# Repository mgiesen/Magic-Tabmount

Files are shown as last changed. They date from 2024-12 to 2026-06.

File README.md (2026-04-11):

# Magic Tabmount

Der "Magic Tabmount" ist eine smarte Wandhalterung für das iPad (Generation 5 bis 9). Durch ein integriertes Magnetsystem kann das iPad mit einem Handgriff an der Wand befestigt oder wieder entfernt werden.

Ferner verfügt die Baugruppe über eine integrierte Schaltung, die mittels Radarwellen die Anwesenheit von Personen um das iPad herum detektiert. Werden Personen erkannt, wird das iPad Display aktiviert und bei Abwesenheit deaktiviert.

## Projektmotivation

Insbesondere die älteren iPad Modelle entsprechen heute nur noch selten den Leistungsanforderungen ihrer Nutzer. Aufgrund des geringen Wiederverkaufswerts enden sie entsprechend häufig ungenutzt in der Schublade. Eine Wandmontage ermöglicht verschiedene Anwendungsmöglichkeiten, für die auch eine ältere Hardware noch geeignet ist. Zum Beispiel:

- Smart Home Steuerungszentrale
- Familien Planer
- Musik Steuerungszentrale
- Dashboards für Fitness/ Stromverbrauch etc.
- Ticker und Nachrichten
- und viele mehr...

Ästhetisch war es mir wichtig, das originale Look and Feel des iPads beizubehalten. Um das Gerät scheinbar unsichtbar montieren zu können, wird auf die Geräterückseite ein Magnetring geklebt, der an der iPad Halterung passgenau gehalten wird.

Die automatische Aktivierung des Displays bei Annäherung fühlt sich nicht nur magisch an, sondern spart auch Zeit und erfordert nicht den Einsatz der Hände, was insbesondere beim Kochen nützich ist.

https://github.com/user-attachments/assets/be153968-7474-4deb-8c27-1ca8d5477d2e

## Technische Challange

In erster Linie ist das Projekt eine technische Challange, denn Apple stellt keine Schnittstelle bereit, um den Aktivierungszustand des Displays zu steuern. Für eine gute Nutzbarkeit in geschützem privaten Umfeld war es jedoch wichtig, dass die zuletzt geöffnete App direkt nach Aktivierung des Displays sichtbar wird.

Um auch den notwendigen Zwischenschritt des "Entsperrens" zu umgehen, habe ich mir ein iPad Display Cover näher angesehen. Klappt man dieses zu und wieder auf, wird das iPad bei deaktiviertem Pincode automatisch entsperrt.

Hierzu verfügt das iPad über zwei magnetoresistive Sensoren, die erkennen, dass ein Smart Cover montiert ist und ob dieses auf- oder zugeklappt ist. Mit einer speziellen Folie, lassen sich die im Cover verbauten Magnete sichtbar machen. Die zwei runden Magnete sind für die Sperrung/Entsperrung des Displays erforderlich.

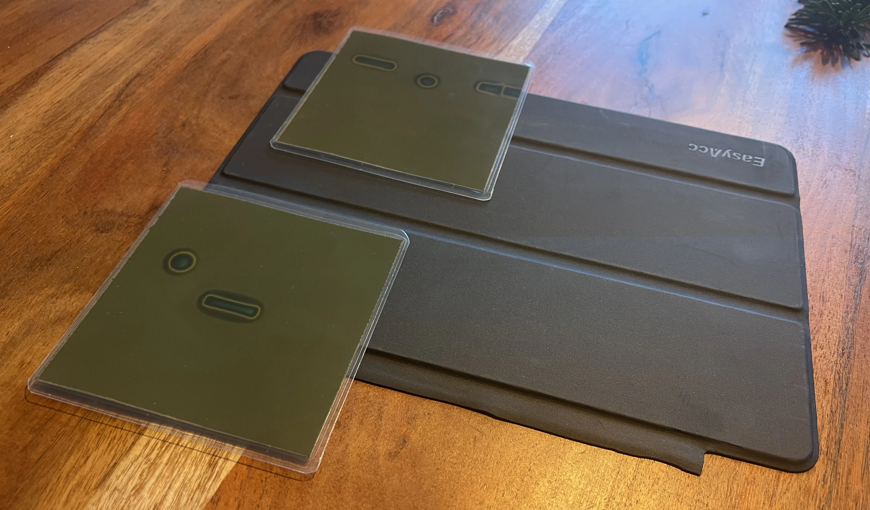
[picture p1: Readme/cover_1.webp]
Cover


## Integrierte Schaltung

Die Wandhalterung positioniert einen Permanentmagneten an der oberen linken Gerätekante, um die Anwesenheit eines Smart Covers zu simulieren. Ein zweiter Magnet an der unteren Geräteseite sperrt das Display bei Anwesenheit und entsperrt es bei Abwesenheit. Stellt man die automatische Displaysperre des iPads aus, kann der Displayzustand vollständig durch den iPad Halter bestimmt werden.

Der Einsatz eines Elektromagneten an der unteren Geräteseite liegt initial auf der Hand. Jedoch ist der im iPad verbaute Magnetsensor auf der Geräteoberseite verbaut. Daher muss ein besonders starkes Magnetfeld aufgebaut werden, welches geeignet ist den Sensor durch Gehäuse, Akku und Display hindurch zu aktivieren. Der Einsatz eines Elektromagneten würde hier zu einem hohen permaneten Stromverbrauch führen.

Daher habe ich mich dazu entschlossen, einen starken Neodymmagnet einzusetzen, der durch einen kleinen Stepper Motor verschoben wird. Dies führt zu einem minimalen Stromverbrauch, da nur beim Änderung des Displayzustandes Energie benötigt wird.

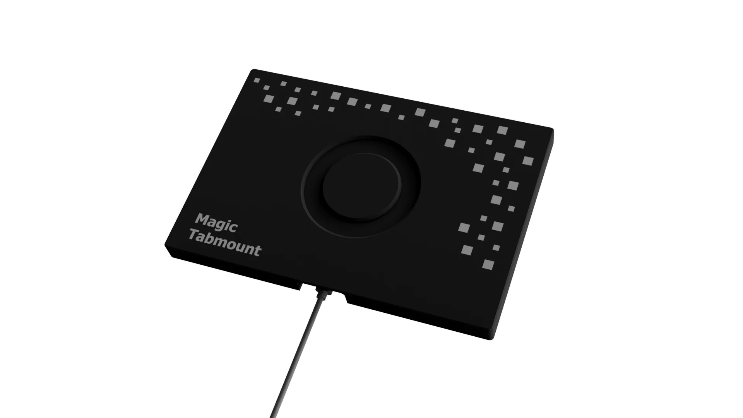
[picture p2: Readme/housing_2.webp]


In Summe integriert die Schaltung entsprechend einen mmWave-Radarsensor, zur Anwesenheitserkennung von Personen, einen kleinen Stepper Motor zur Verschiebung des Magneten, sowie entsprechender Steuerungselektronik.

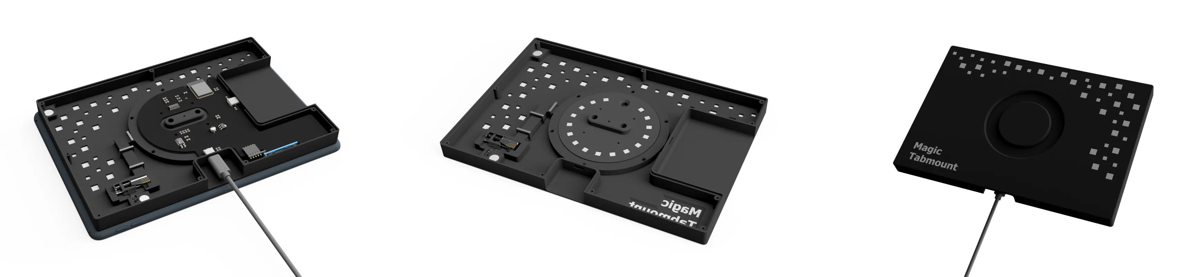
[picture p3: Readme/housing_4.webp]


## Planung der Elektronik

Um den Stromanschluss der Platine mit einer Lademöglichkeit des iPads zu kombinieren, habe ich zwei USB C Anschlüsse auf der Platine verbaut. Der nach unten ausgerichtete Port, ist für ein Stromkabel vorgesehen. Der zweite Port ist auf gleicher Höhe wie der Lightning Anschluss des iPads positioniert. Somit kann ein kurzes Verbindungskabel zwischen iPad und Wandhalterung zum Laden des iPads eingesetzt werden.

Zur Auswertung der Signale und Steuerung der Logik ist ein Mikrocontroller verbaut, der direkt über den Host Port programmiert werden kann. Zur Steuerung des Motors wird zudem ein Stepper Treiber benötigt. Der Umfang der Elektronik und entsprechender Komplexität erfordert ein Custom-PCB Design, welches ich mit KiCad umgesetzt habe.

Für eine besondere, persönliche Note, habe ich das vorderseitige Produktlogo aus Semi-Transparentem Material gedruckt, um es aktiv zu hinterleuchten. Somit integriert die Platine zusätzlich vier RGB LEDs, die über den Mikrocontroller gesteuert werden. Ein rückseitig verbauter Hall-Sensor prüft, ob das iPad anliegt, oder nicht. Sobald das iPad angelegt ist, wird die Logobeleuchtung ausgeschlatet.

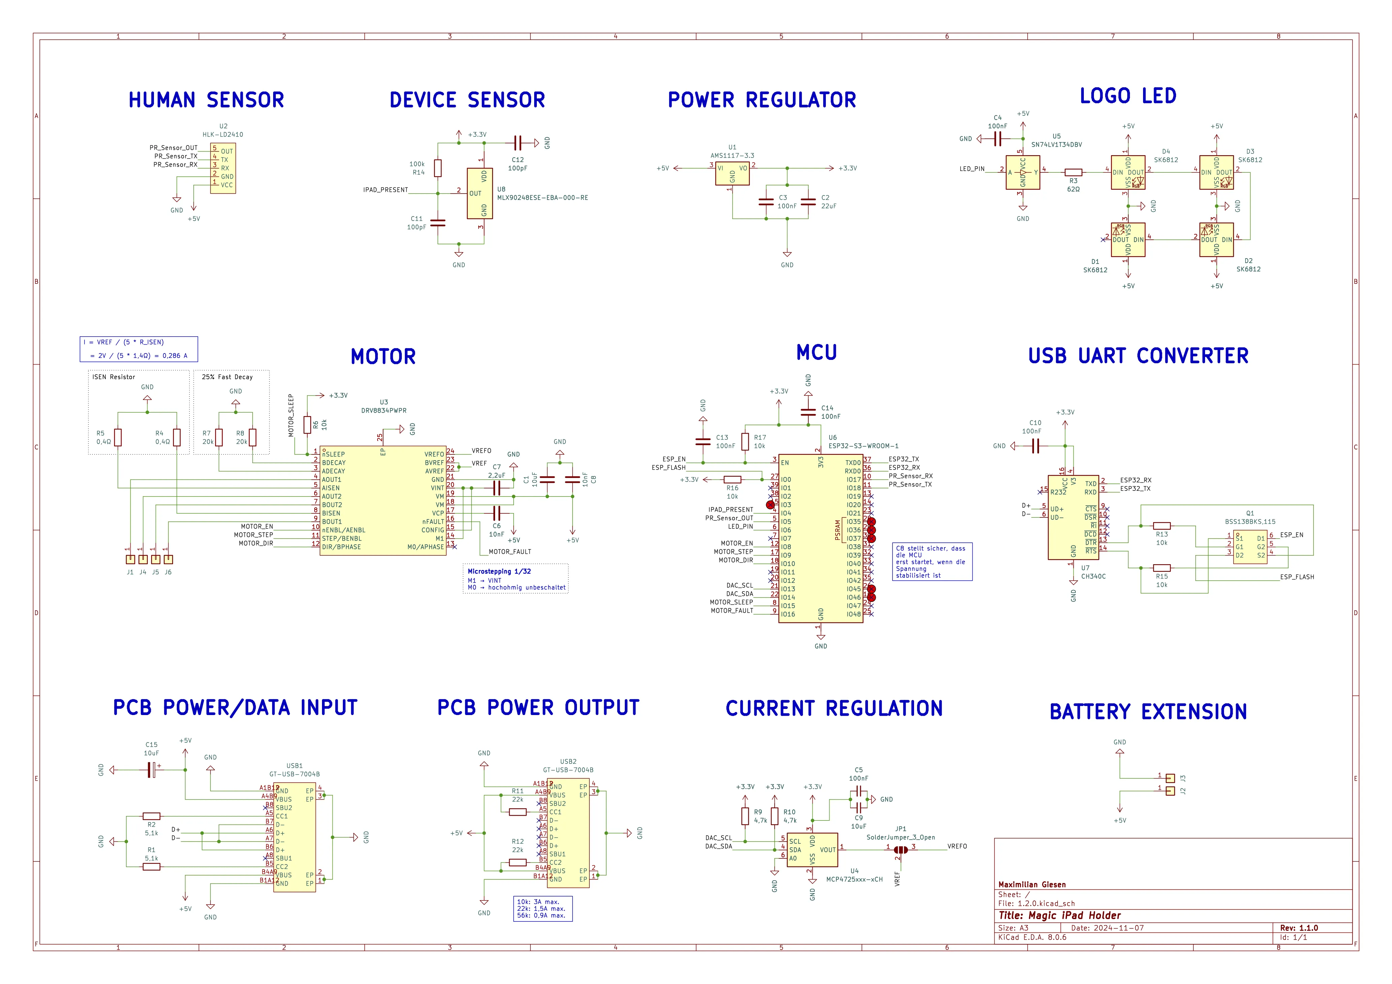
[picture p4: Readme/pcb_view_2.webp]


### PCB Layout

Aufgrund der hohen Anzahl an Elektronik Komponenten, habe ich versucht ausschließlich auf SMD Komponenten zu setzen, sodass ich einen Großteil der Komponetnten mittels Stencil bestücken konnte. Funktionsbedingt musste lediglich der Hall Sensor zur Geräteerkennung, als auch die Logobeleuchtung auf die Unterseite des PCBs gelegt werden.

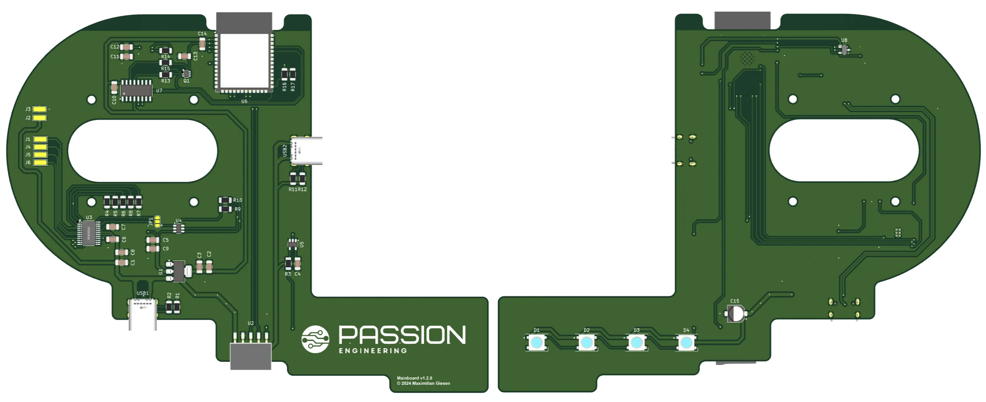
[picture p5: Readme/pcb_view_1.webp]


### Ergebnis

Mittels Stencil und Hot-Plate ließen sich alle Komponenten schnell und einfach verlöten. Das PCB wird mit vier Schrauben im Gehäuse befestigt und der Stepper Motor am Platinenrand verlötet. Für die Zukunft wäre ein Stecker praktikabeler, jedoch war diese Lösung kurzfristig am kostengünstigsten.

Die seitliche Tasche ermöglicht es ein Standard USB C auf Lightning Kabel einzurollen und das Gerät über einen Winkeladapter zu laden.

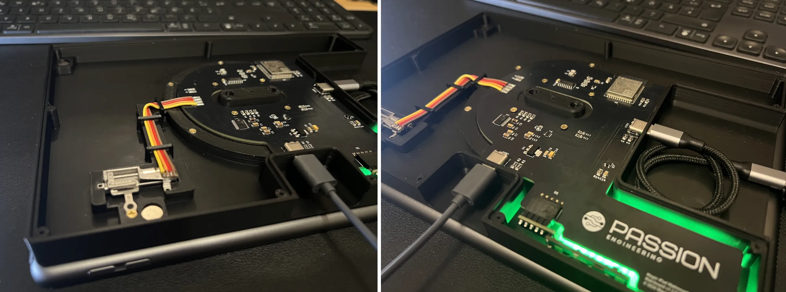
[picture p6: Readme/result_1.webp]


## Gehäuse

Während des Prototypings und ohne sonderlichen Fokus auf einen marketingtauglichen Namen, lief der Wandhalter unter dem Projektnamen "Magic iPad Wallmount". Um keine Markenrechte zu verletzten, änderte ich den Namen zum Projektende auf Magic Tabmount.

Das Gehäusedesign sollte initial kleinstmöglich und funktionsorientiert gestaltet sein.

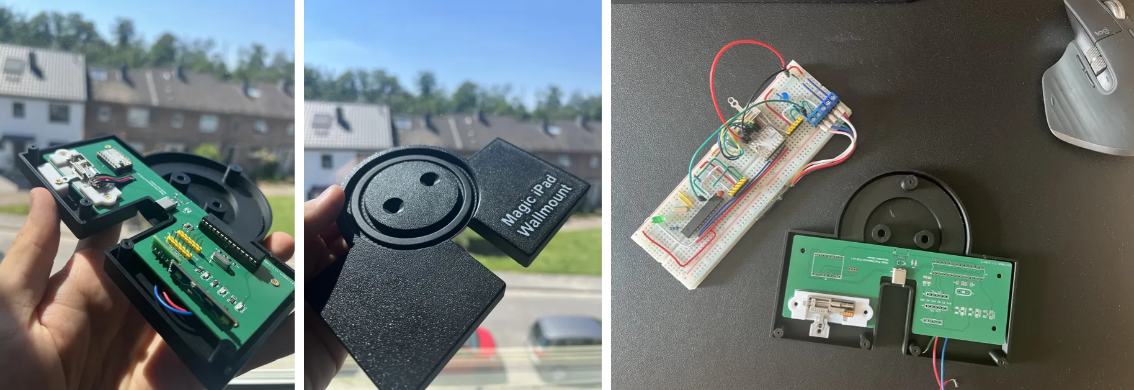
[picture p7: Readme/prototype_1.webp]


Problemtaisch war der Magnet an der oberen Geräteecke, ohne den eine Steuerung des Displays nicht möglich war. Der zuerst aufgeklebte Magnet störte bei der Bedienung des Tablets in der Hand, weswegen ich das Design an die Gerätemaße anglich, um den Magnet zu integrieren.

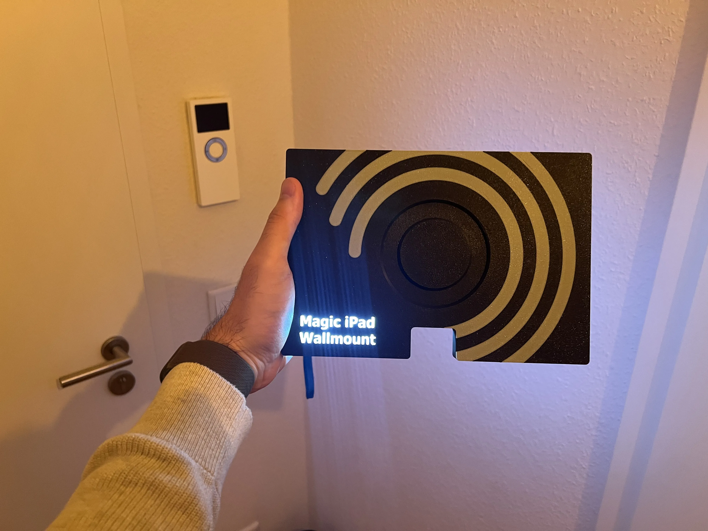
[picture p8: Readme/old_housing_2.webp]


Hinter einer kraftschlüssig aufgesetzten Kappe, liegen zwei Schraubpunkte, über die der Halter an der Wand montiert werden kann.

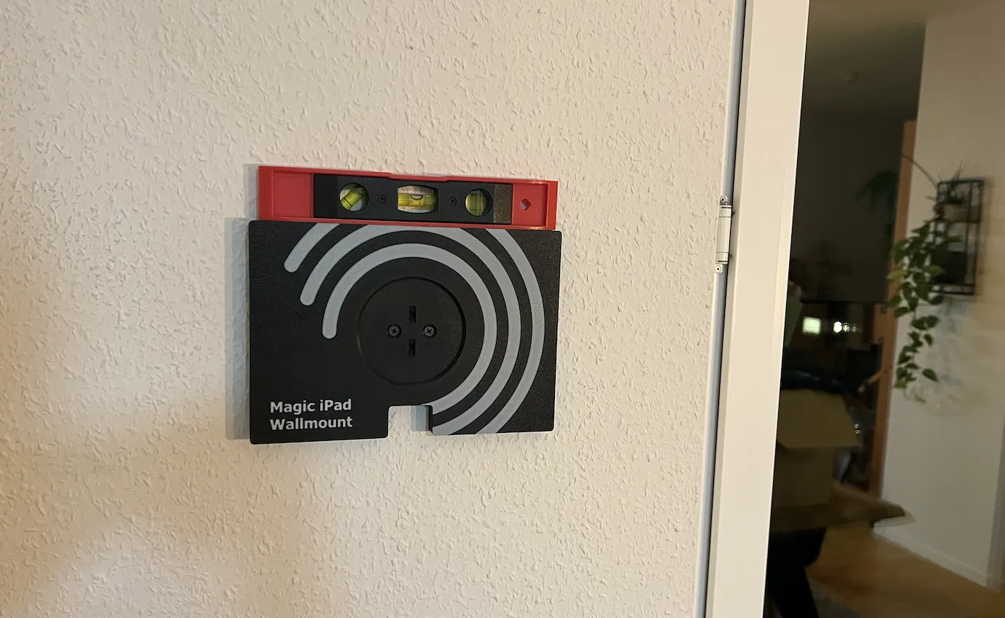
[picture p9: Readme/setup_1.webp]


Für eine gute Druckbarkeit des Gehäuses und einheitliche Oberflächen, mussten alle Oberseiten auf der Druckplatte des 3D Druckers aufliegen.

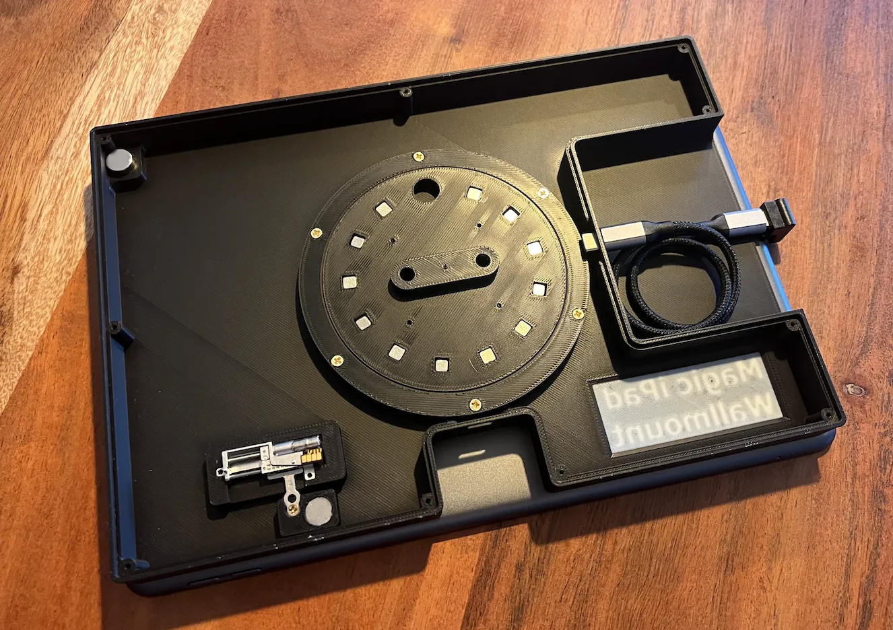
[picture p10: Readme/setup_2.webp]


Daher ist der innere Ring mehrteilig gedruckt und anschließend formschlüssig montiert und verschraubt.

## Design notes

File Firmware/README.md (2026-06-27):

# Firmware

ESP32-S3-Firmware des Magic Tabmount. Sie steuert den Display-Magneten (Stepper-Motor), die Logo-LEDs und die Anwesenheitserkennung (LD2410-Radar) und stellt ein Konfigurations-Dashboard über einen WLAN-Access-Point bereit.

## Voraussetzungen

- [PlatformIO](https://platformio.org/) (CLI oder VS-Code-Erweiterung)
- Board: `esp32-s3-devkitc-1` (in `platformio.ini` vorkonfiguriert)

Externe Bibliotheken lädt PlatformIO automatisch anhand der `lib_deps` in `platformio.ini` — ein manueller Schritt ist nicht nötig. Projekteigene Bibliotheken liegen direkt unter `lib/` (`DeviceDetection`, `DisplayController`). Das Projekt nutzt **keine** Git-Submodule.

## Bauen und Flashen

Es gibt zwei Upload-Ziele:

```bash
# Firmware (src/) bauen und flashen
pio run -t upload

# Web-Dashboard (data/) als LittleFS-Image flashen
pio run -t uploadfs
```

Nach Änderungen an `data/` (HTML/CSS/JS) ist `uploadfs` erforderlich — ein normaler `upload` aktualisiert das Dashboard nicht.

## Konfiguration

Nach dem Start öffnet das Gerät dauerhaft einen WLAN-Access-Point `Magic-Tabmount-<ID>` (Passwort `tabmount`). Die `<ID>` wird aus dem geräteindividuellen Teil der MAC-Adresse abgeleitet und ist je Gerät eindeutig. Das Dashboard ist anschließend unter `http://192.168.4.1` oder `http://Magic-Tabmount.local` erreichbar.

Die Kernsteuerung (Anwesenheitserkennung, Display, LEDs) läuft ab dem Boot unabhängig vom WLAN.

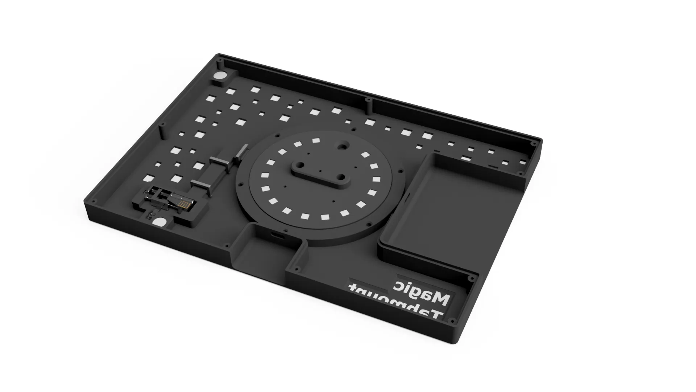
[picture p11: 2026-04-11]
Readme/housing_3.webp

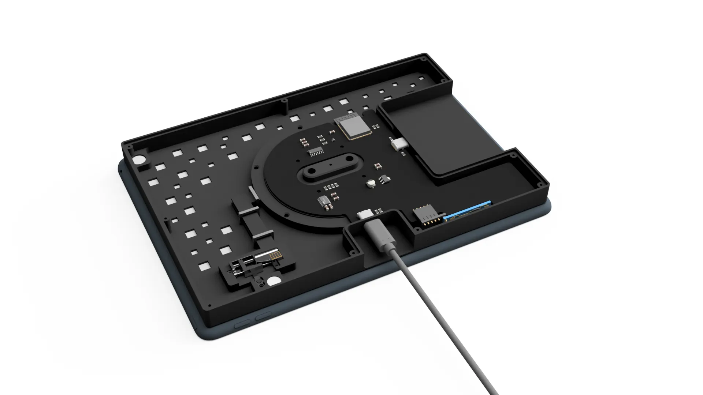
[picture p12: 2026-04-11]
Readme/housing_1.webp

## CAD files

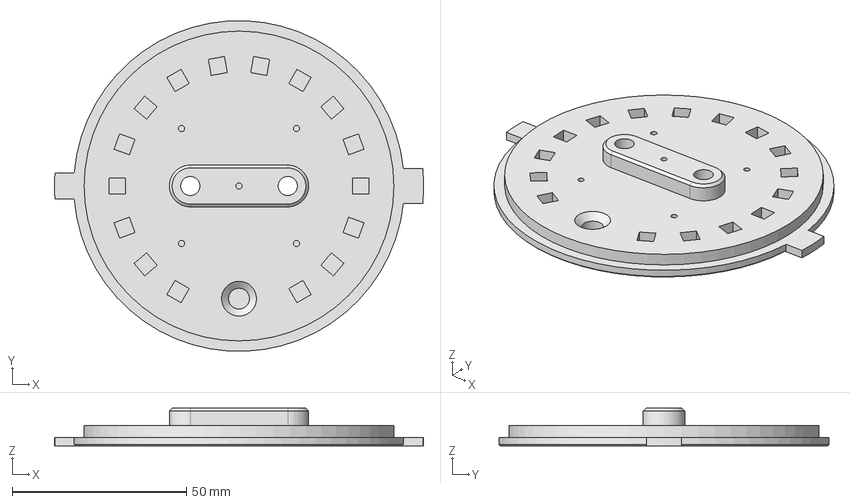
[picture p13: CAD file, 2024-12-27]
Housing/STEP/Mittelteil.stp
106.0 x 94.9 x 10.8 mm

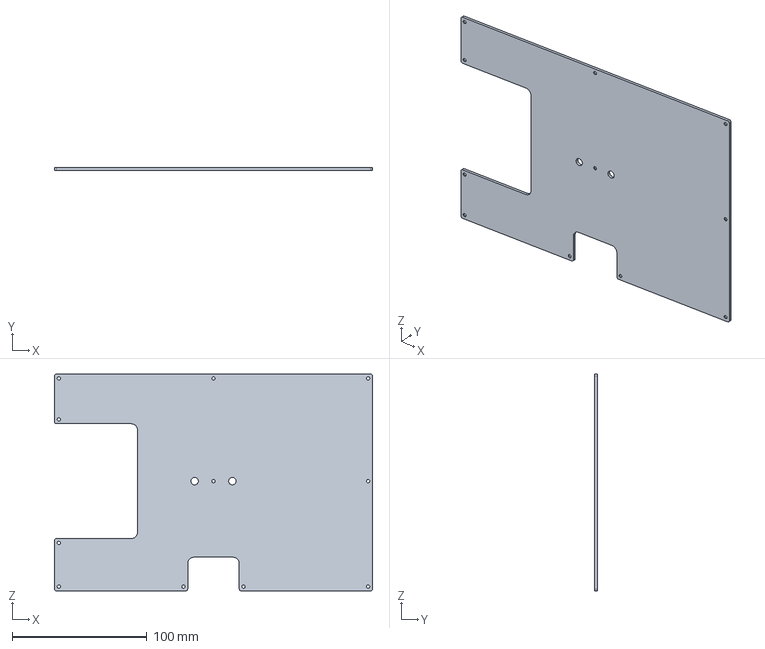
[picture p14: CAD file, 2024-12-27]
Housing/STEP/Gehäuse Deckel.stp
235.8 x 2.00 x 160.8 mm

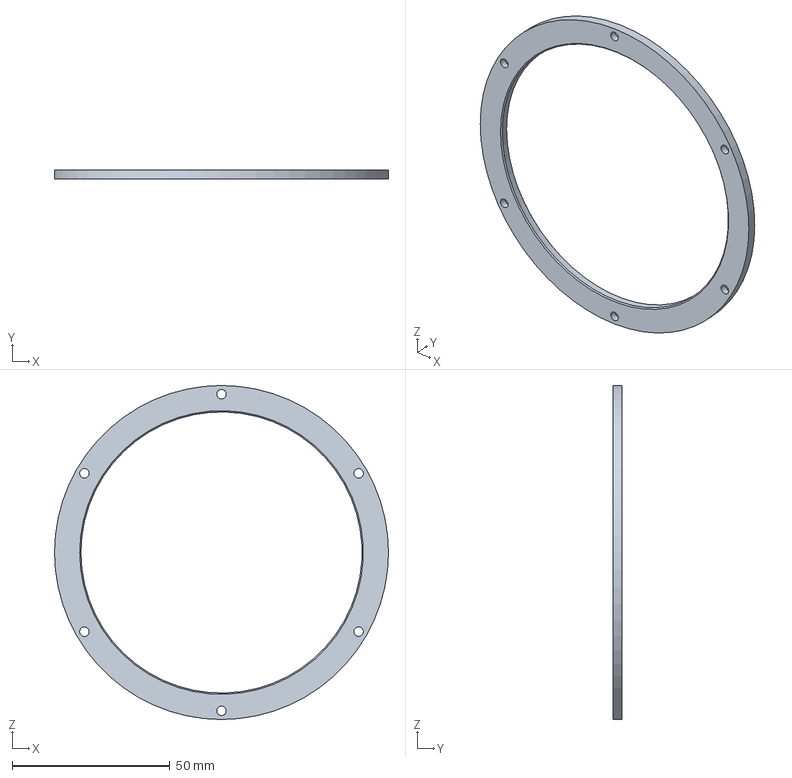
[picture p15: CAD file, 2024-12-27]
Housing/STEP/Klemmrahmen.stp
106.0 x 3.00 x 106.0 mm

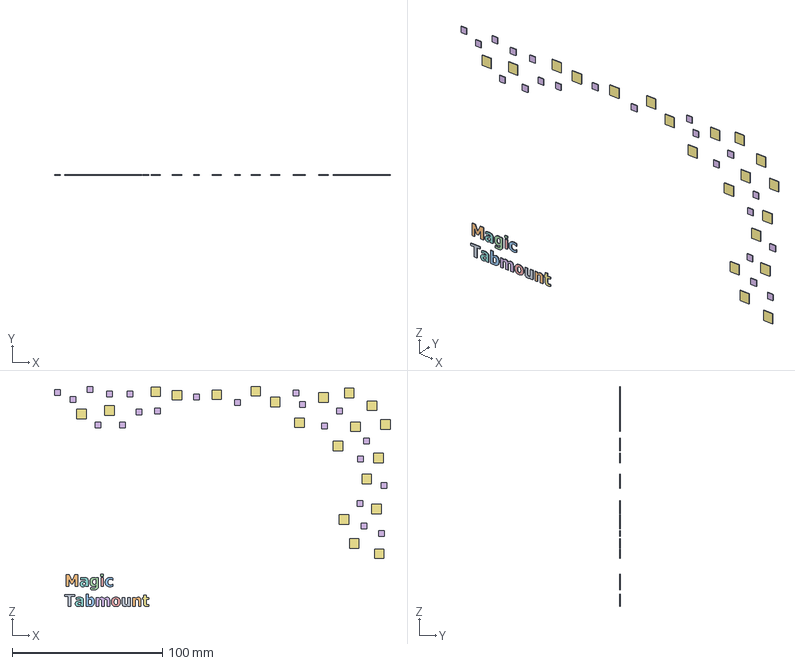
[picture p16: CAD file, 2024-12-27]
Housing/STEP/Gehäuse Infill.stp
223.7 x 0.4 x 146.8 mm

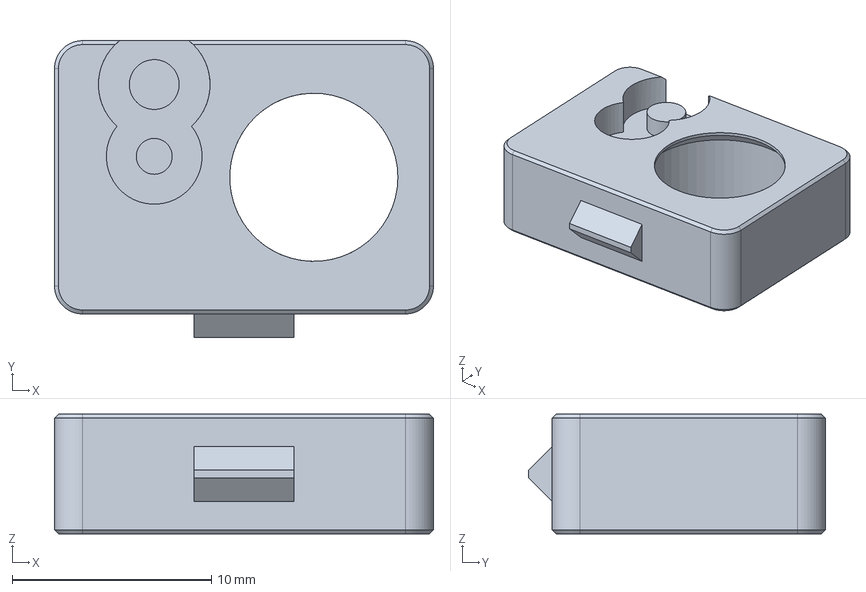
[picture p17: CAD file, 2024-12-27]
Housing/STEP/Magnethalter.stp
19.0 x 14.9 x 6.00 mm

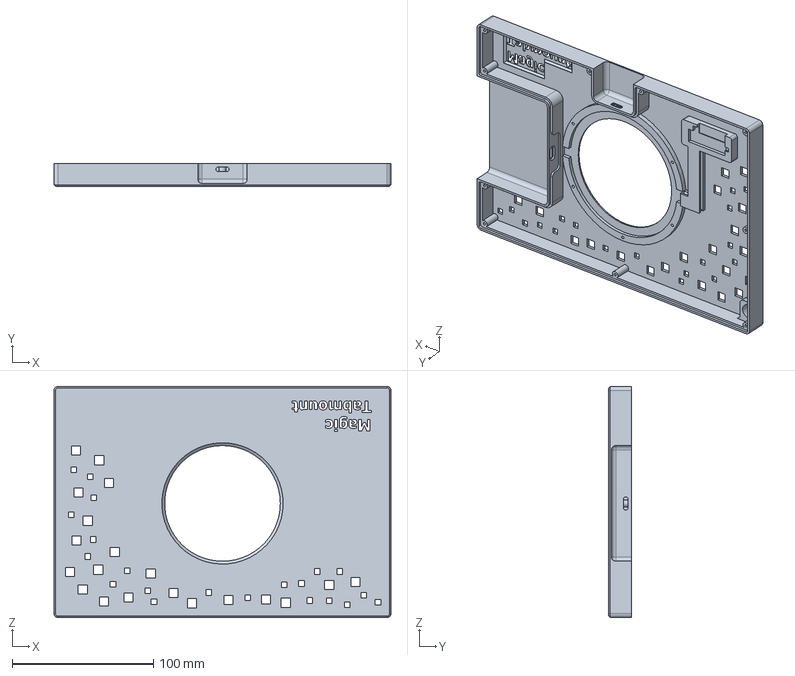
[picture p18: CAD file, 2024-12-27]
Housing/STEP/Gehäuse.stp
239.0 x 16.0 x 164.0 mm

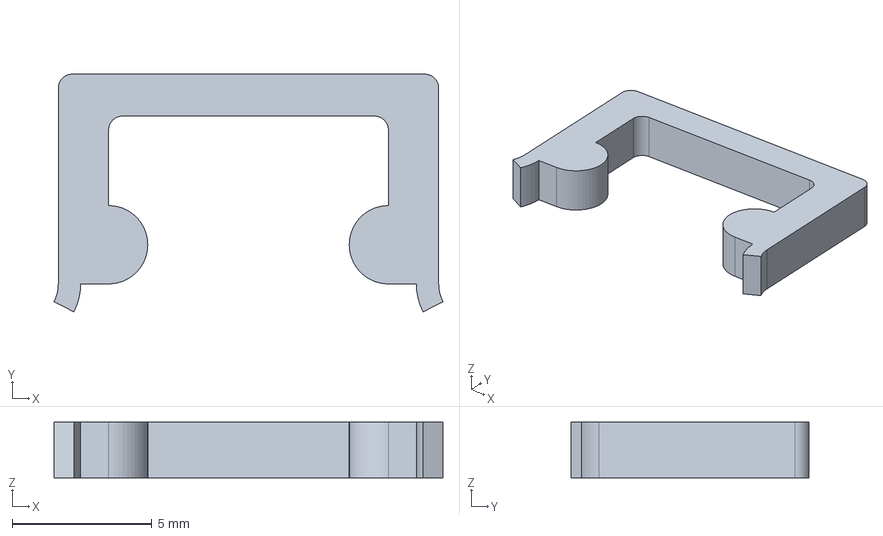
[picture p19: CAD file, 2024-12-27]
Housing/STEP/Kabel Klipser.stp
13.9 x 8.50 x 2.00 mm

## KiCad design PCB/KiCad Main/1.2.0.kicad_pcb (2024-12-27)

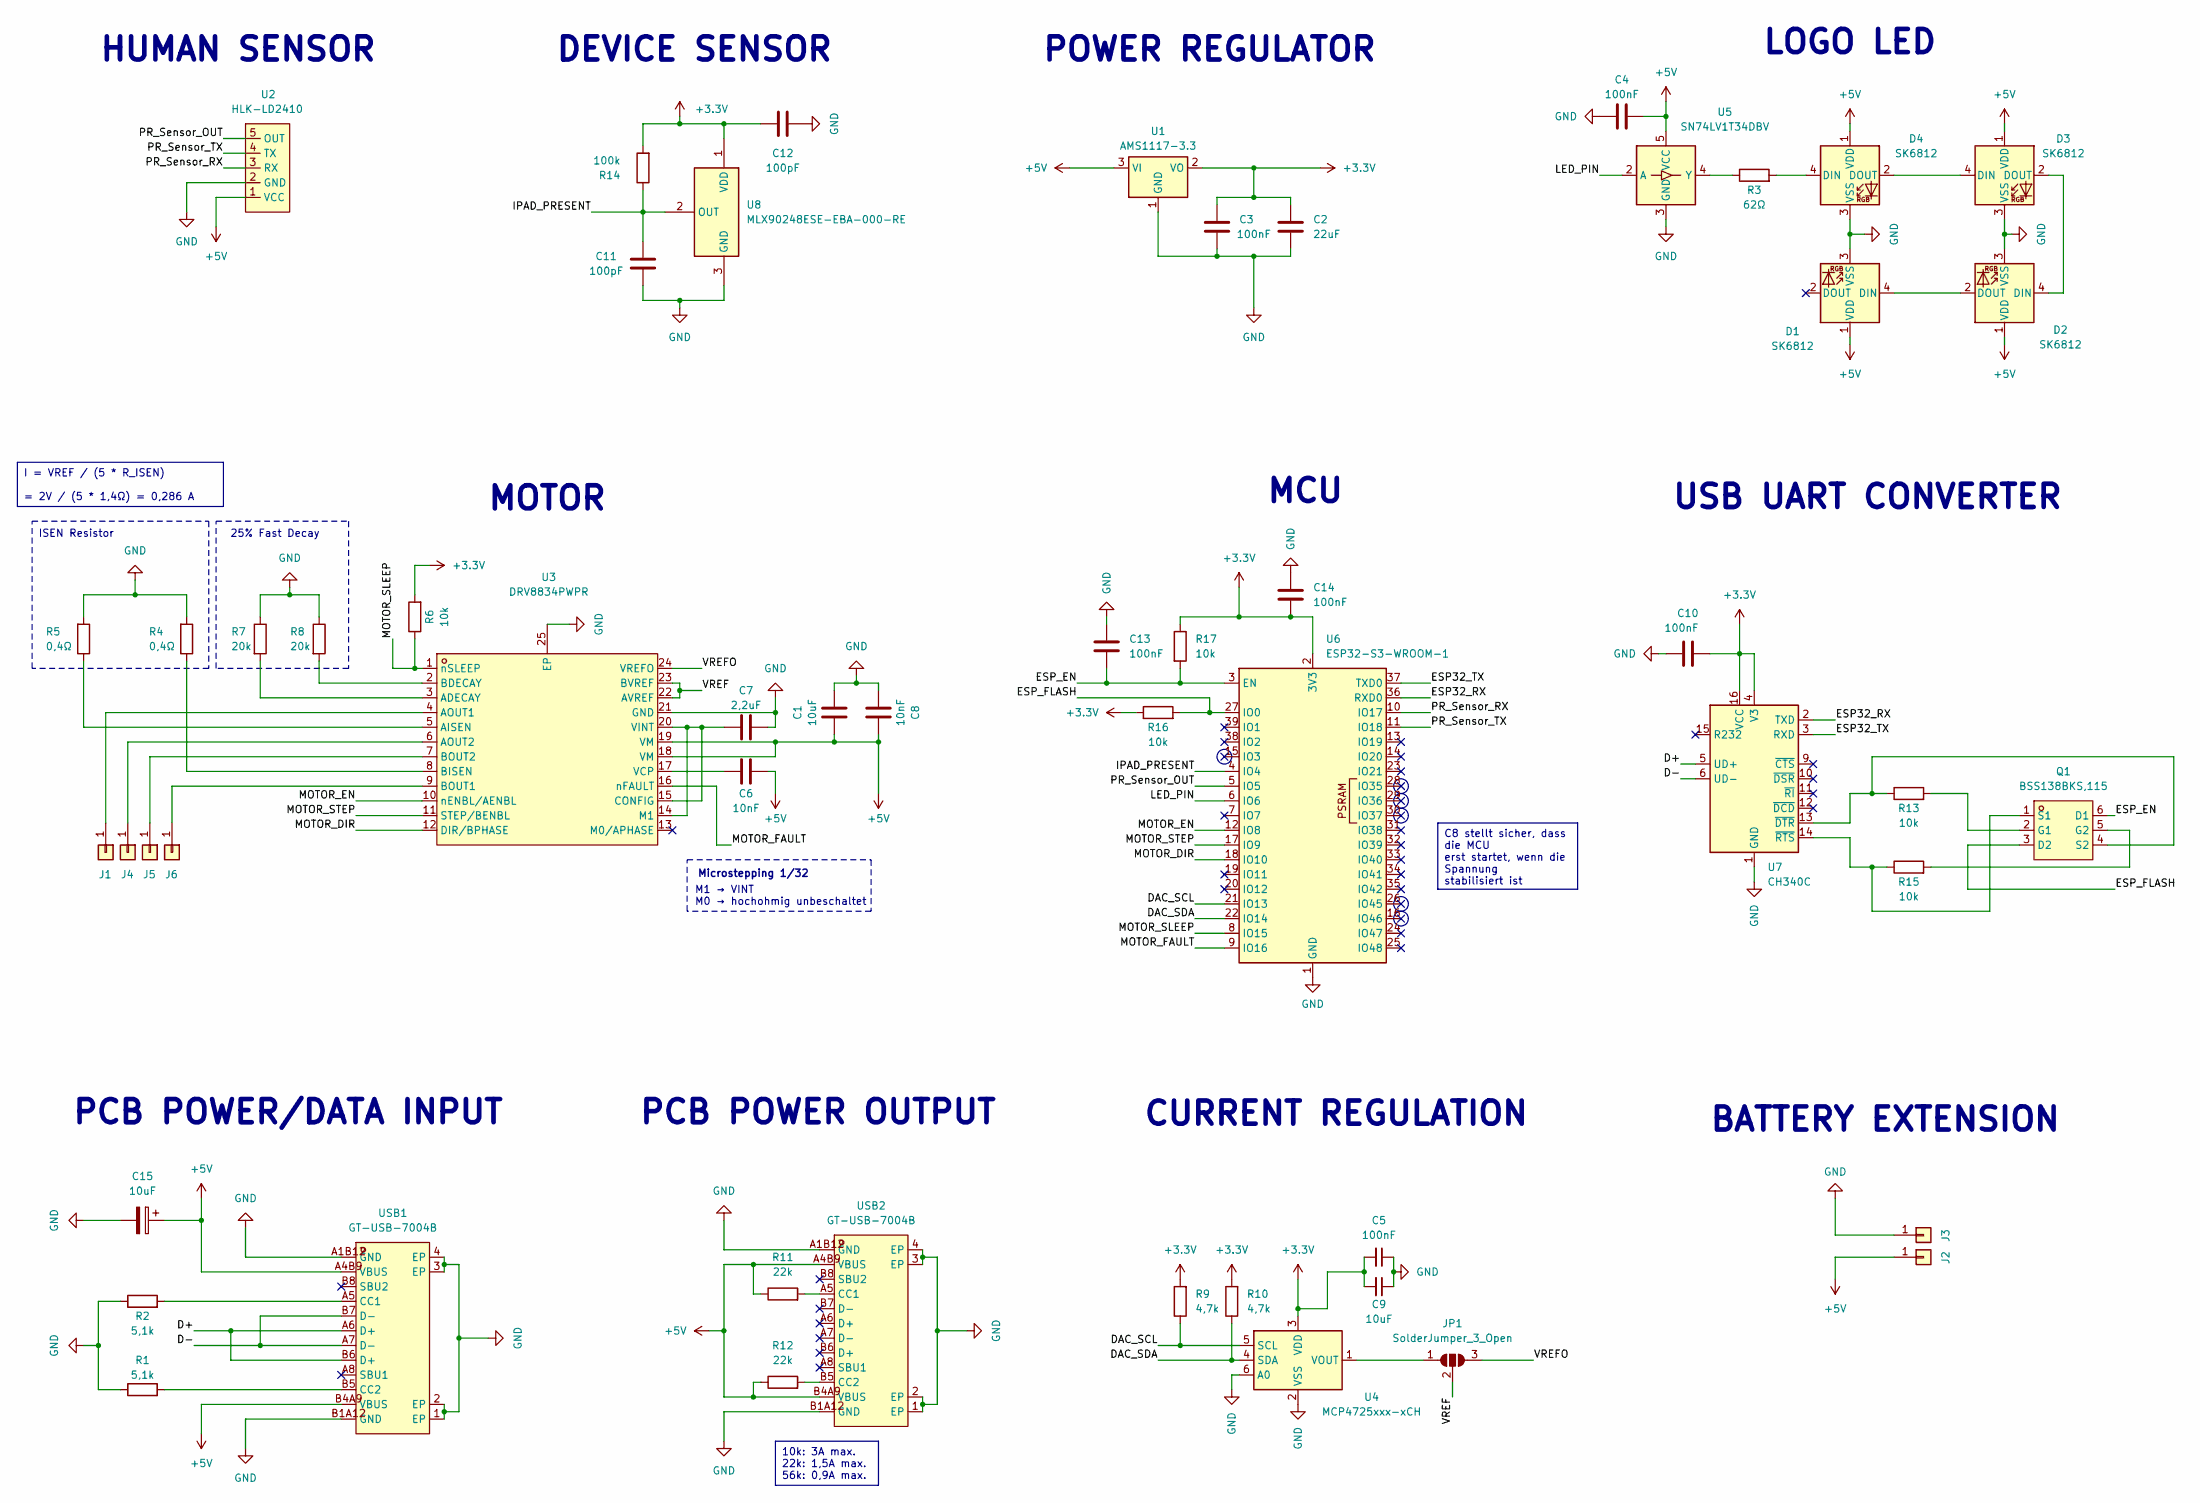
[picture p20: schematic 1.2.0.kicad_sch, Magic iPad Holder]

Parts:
C1: 10uF; C_1206_3216Metric; LCSC Part C13585
C2: 22uF; C_1206_3216Metric; LCSC Part C12891
C3, C10, C13, C14: 100nF; C_1206_3216Metric; LCSC Part C82601
C4: 100nF; C_1206_3216Metric; LCSC Part C107186
C5: 100nF; C_1206_3216Metric
C6, C8: 10nF; C_1206_3216Metric; LCSC Part C77498
C7: 2,2uF; C_1206_3216Metric; LCSC Part C107186
C9: 10uF; C_1206_3216Metric
C11, C12: 100pF; C_1206_3216Metric; LCSC Part C113876
C15: 10uF; CP_Elec_5x3; LCSC Part C340737
D1, D2, D3, D4: SK6812; LED_WS2812B_PLCC4_5.0x5.0mm_P3.2mm; LCSC Part C5380881
J1, J2, J3, J4, J5, J6: Solder Pad; TestPoint_Pad_1.5x1.5mm
JP1: SolderJumper_3_Open; SolderJumper-3_P1.3mm_Open_RoundedPad1.0x1.5mm
Q1: BSS138BKS,115; SOT-363_L2.0-W1.3-P0.65-LS2.1-BR; LCSC Part C456075
R1, R2: 5,1k; R_1206_3216Metric; LCSC Part C163372
R3: 62Ω; R_1206_3216Metric; LCSC Part C17902
R4, R5: 0,4Ω; R_1206_3216Metric; LCSC Part C5126044
R6, R13, R15, R16, R17: 10k; R_1206_3216Metric; LCSC Part C17902
R7, R8: 20k; R_1206_3216Metric; LCSC Part C18003
R9, R10: 4,7k; R_1206_3216Metric; LCSC Part C25830
R11, R12: 22k; R_1206_3216Metric; LCSC Part C25830
R14: 100k; R_1206_3216Metric; LCSC Part C17900
U1: AMS1117-3.3; SOT-223-3_TabPin2; Mouser Part Number 926-LM1117MPX3.3NOPB; LCSC Part C347222
U2: HLK-LD2410; HDR-SMD_5P-P2.54-H-F_X6511FRS-19-C85D30; LCSC Part C5183133
U3: DRV8834PWPR; HTSSOP-24_L7.8-W4.4-P0.65-BL-EP; Mouser Part Number 595-DRV8834PWP; LCSC Part C456273
U4: MCP4725xxx-xCH; SOT-23-6
U5: SN74LV1T34DBV; SOT-23-5
U6: ESP32-S3-WROOM-1; Mouser Part Number 356-ESP32-S3WROOM1N8; LCSC Part C2913198
U7: CH340C; SOIC-16_3.9x9.9mm_P1.27mm; LCSC Part C84681
U8: MLX90248ESE-EBA-000-RE; SOT95P280X100-3N; Mouser Part Number 482-90248ESEEBA000RE
USB1, USB2: GT-USB-7004B; USB-C-SMD_GT-USB-7004B; LCSC Part C5368946

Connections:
+3.3V: C2.1, C3.2, C5.2, C9.2, C10.1, C12.2, C14.1, R6.2, R9.2, R10.2, R14.2, R16.1, R17.1, U1.2 (VO), U4.3 (VDD), U6.2 (3V3), U7.4 (V3), U7.16 (VCC), U8.1 (VDD)
+5V: C1.1, C4.2, C6.2, C8.2, C15.1, D1.1 (VDD), D2.1 (VDD), D3.1 (VDD), D4.1 (VDD), J2.1, R11.1, R12.1, U1.3 (VI), U2.1 (VCC), U3.18 (VM), U3.19 (VM), U5.5 (VCC), USB1.A4B9 (VBUS), USB1.B4A9 (VBUS), USB2.A4B9 (VBUS), USB2.B4A9 (VBUS)
/D+: U7.5 (UD+), USB1.A6 (D+), USB1.B6 (D+)
/D-: U7.6 (UD-), USB1.A7 (D-), USB1.B7 (D-)
/DAC_SCL: R9.1, U4.5 (SCL), U6.21 (IO13)
/DAC_SDA: R10.1, U4.4 (SDA), U6.22 (IO14)
/ESP32_RX: U6.36 (RXD0), U7.2 (TXD)
/ESP32_TX: U6.37 (TXD0), U7.3 (RXD)
/ESP_EN: C13.1, Q1.6 (D1), R17.2, U6.3 (EN)
/ESP_FLASH: Q1.3 (D2), R16.2, U6.27 (IO0)
/IPAD_PRESENT: C11.2, R14.1, U6.4 (IO4), U8.2 (OUT)
/LED_PIN: U5.2 (A), U6.6 (IO6)
/MOTOR_DIR: U3.12 (DIR/BPHASE), U6.18 (IO10)
/MOTOR_EN: U3.10 (nENBL/AENBL), U6.12 (IO8)
/MOTOR_FAULT: U3.16 (nFAULT), U6.9 (IO16)
/MOTOR_SLEEP: R6.1, U3.1 (nSLEEP), U6.8 (IO15)
/MOTOR_STEP: U3.11 (STEP/BENBL), U6.17 (IO9)
/PR_Sensor_OUT: U2.5 (OUT), U6.5 (IO5)
/PR_Sensor_RX: U2.3 (RX), U6.10 (IO17)
/PR_Sensor_TX: U2.4 (TX), U6.11 (IO18)
/VREF: JP1.2 (C), U3.22 (AVREF), U3.23 (BVREF)
/VREFO: JP1.3 (B), U3.24 (VREFO)
GND: C1.2, C2.2, C3.1, C4.1, C5.1, C7.2, C8.1, C9.1, C10.2, C11.1, C12.1, C13.2, C14.2, C15.2, D1.3 (VSS), D2.3 (VSS), D3.3 (VSS), D4.3 (VSS), J3.1, R1.1, R2.1, R4.2, R5.2, R7.1, R8.1, U1.1 (GND), U2.2 (GND), U3.21 (GND), U3.25 (EP), U4.2 (VSS), U4.6 (A0), U5.3 (GND), U6.1 (GND), U6.40 (GND), U6.41 (GND), U7.1 (GND), U8.3 (GND), USB1.1 (EP), USB1.2 (EP), USB1.3 (EP), USB1.4 (EP), USB1.A1B12 (GND), USB1.B1A12 (GND), USB2.1 (EP), USB2.2 (EP), USB2.3 (EP), USB2.4 (EP), USB2.A1B12 (GND), USB2.B1A12 (GND)
unnamed: D1.4 (DIN), D2.2 (DOUT)
unnamed: D2.4 (DIN), D3.2 (DOUT)
unnamed: D3.4 (DIN), D4.2 (DOUT)
unnamed: D4.4 (DIN), R3.2
unnamed: J1.1, U3.4 (AOUT1)
unnamed: J4.1, U3.6 (AOUT2)
unnamed: J5.1, U3.7 (BOUT2)
unnamed: J6.1, U3.9 (BOUT1)
unnamed: JP1.1 (A), U4.1 (VOUT)
unnamed: Q1.2 (G1), R13.2
unnamed: Q1.5 (G2), R15.2
unnamed: Q1.1 (S1), R15.1, U7.14 (~RTS)
unnamed: Q1.4 (S2), R13.1, U7.13 (~DTR)
unnamed: R7.2, U3.3 (ADECAY)
unnamed: R5.1, U3.5 (AISEN)
unnamed: R8.2, U3.2 (BDECAY)
unnamed: R4.1, U3.8 (BISEN)
unnamed: C7.1, U3.14 (M1), U3.15 (CONFIG), U3.20 (VINT)
unnamed: C6.1, U3.17 (VCP)
unnamed: R3.1, U5.4 (Y)
unnamed: R2.2, USB1.A5 (CC1)
unnamed: R1.2, USB1.B5 (CC2)
unnamed: R11.2, USB2.A5 (CC1)
unnamed: R12.2, USB2.B5 (CC2)

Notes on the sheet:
C8 stellt sicher, dass die MCU erst startet, wenn die Spannung stabilisiert ist
10k: 3A max. 22k: 1,5A max. 56k: 0,9A max.
I = VREF / (5 * R_ISEN) = 2V / (5 * 1,4Ω) = 0,286 A
Microstepping 1/32
CURRENT REGULATION
MCU
MOTOR
PCB POWER OUTPUT
PCB POWER/DATA INPUT
HUMAN SENSOR
USB UART CONVERTER
LOGO LED
M1 → VINT M0 → hochohmig unbeschaltet
BATTERY EXTENSION
POWER REGULATOR
25% Fast Decay
DEVICE SENSOR
ISEN Resistor

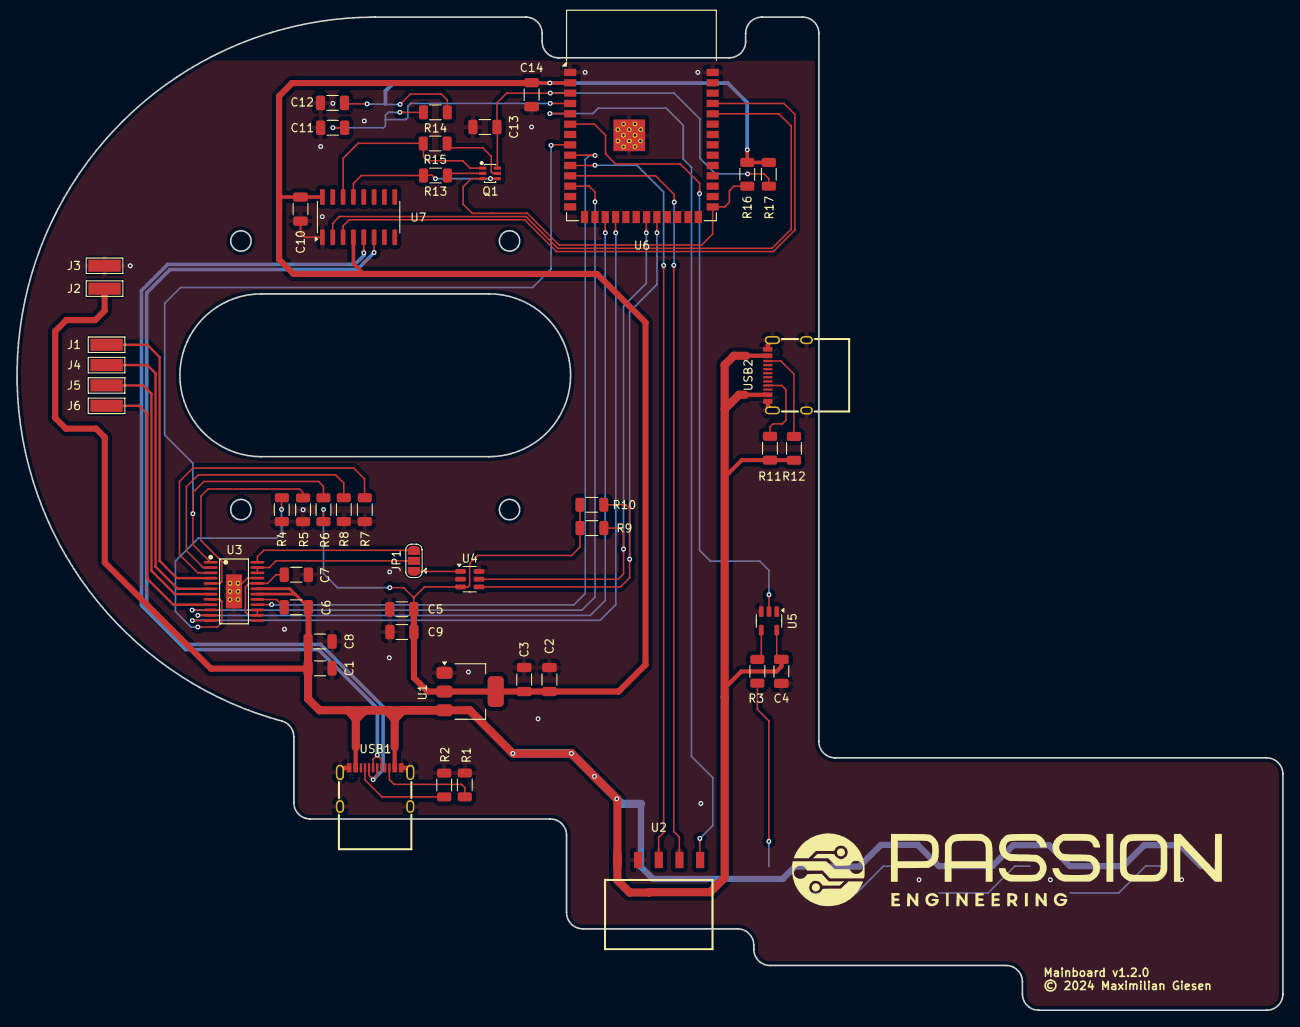
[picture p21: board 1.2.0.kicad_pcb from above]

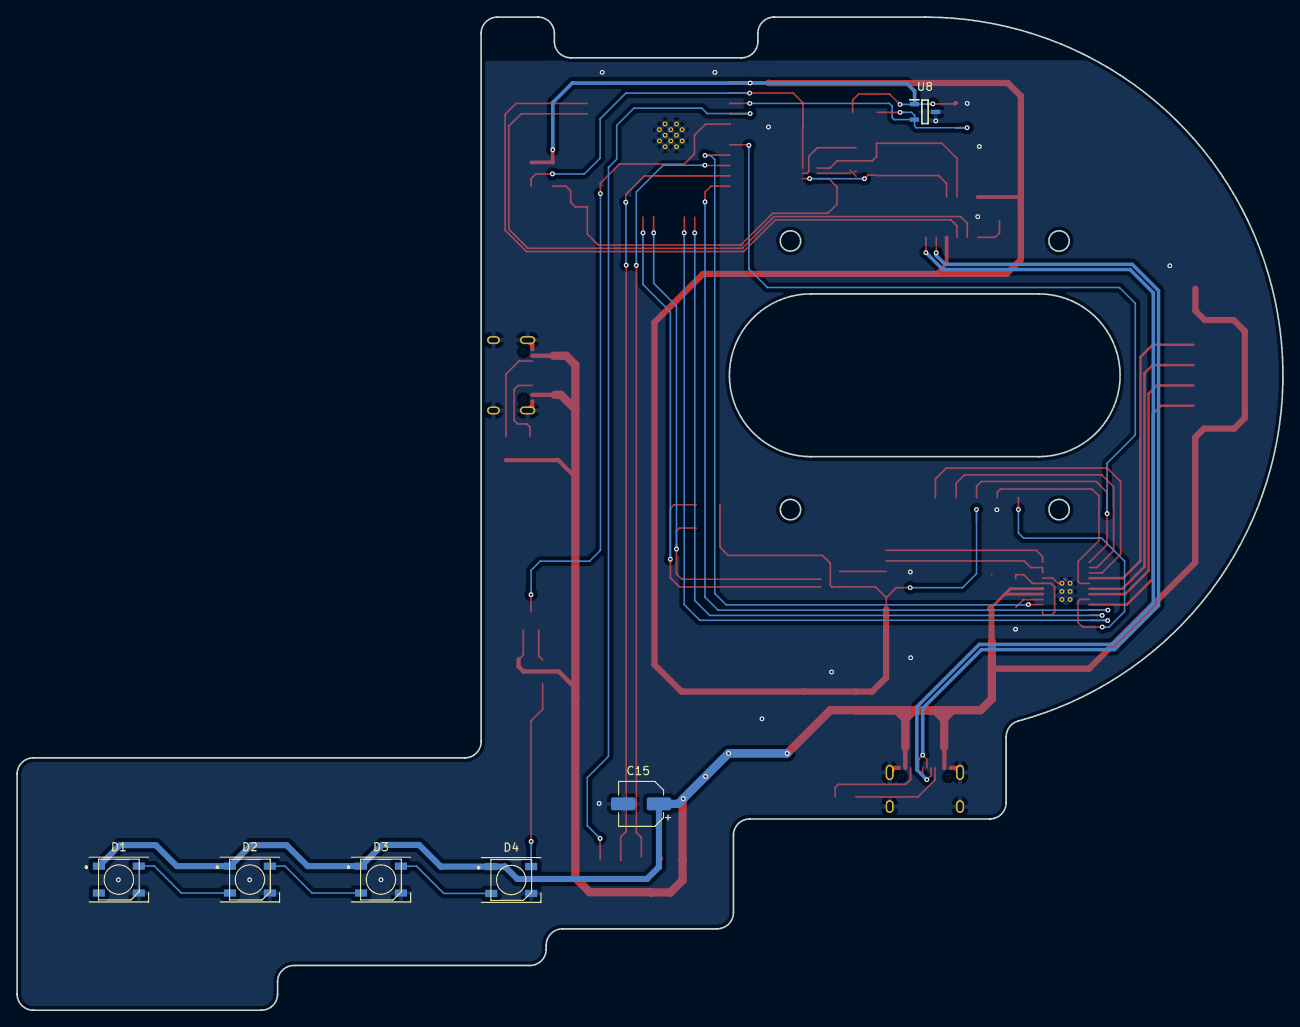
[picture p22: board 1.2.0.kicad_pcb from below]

Board: 2 copper layers, 155.5 x 122.0 mm, 54 parts (6 on the bottom side), 47 nets.

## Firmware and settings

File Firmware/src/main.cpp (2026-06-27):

// ************************************************************************
// Magic Tabmount - Firmware
//
// Der ESP32 oeffnet ab dem Start einen dauerhaften WLAN-Access-Point
// (Magic-Tabmount-<hex>, PW: tabmount) und hostet darueber ein Dashboard
// (LittleFS + WebSocket /ws). Die Kernsteuerung laeuft unabhaengig davon
// ab Boot weiter (kein WLAN noetig).
//
// Architektur (klar getrennte Verantwortlichkeiten):
//   - Eingaenge : Hall-Sensor (iPad anliegend, ISR) + LD2410-Radar (Person, UART)
//   - Policy    : controlStep() ist die EINZIGE Stelle, die Aktoren ansteuert.
//                 Sie berechnet aus Modus + Sensoren die Soll-Ausgaenge.
//   - Aktoren   : Stepper-Motor (Display-Trigger), NeoPixel-Logo-LED
//
// Betriebsmodi:
//   - Automatik (Default): Display folgt der Anwesenheit (nur wenn ein iPad
//     anliegt); LED nur an wenn KEIN iPad anliegt, Farbe weiss/blau je Person.
//   - Manuell: Nutzer steuert Display + Logo-Farbe ueber das Dashboard.
//
// Nebenlaeufigkeit (ESP32-S3 ist Dual-Core): ISR und WebSocket-Handler setzen
// Soll-/Flag-Variablen. Jede Hardware-Ressource wird nur aus genau einem Kontext
// bedient (Motor, Logo-LED und Radar im loop(); DAC im WS-Handler). NVS wird aus
// beiden Kontexten geschrieben, ist dort aber intern serialisiert.
// ************************************************************************

#include <Arduino.h>
#include <Wire.h>
#include <Preferences.h>
#include <WiFi.h>
#include <ESPmDNS.h>
#include <AsyncTCP.h>
#include <ESPAsyncWebServer.h>
#include <LittleFS.h>
#include <Adafruit_NeoPixel.h>
#include <Adafruit_MCP4725.h>
#include <ArduinoJson.h>
#include <MyLD2410.h>

#include "DeviceDetection.h"
#include "DisplayController.h"

// ************************************************************************
// Pin- und Konstanten-Definitionen
// ************************************************************************

#define DEBUG_SERIAL Serial
#define HOSTNAME "Magic-Tabmount"

// WLAN-Access-Point: dauerhaft offen (Konfiguration/Dashboard).
#define AP_SSID_PREFIX "Magic-Tabmount-"
#define AP_PASSWORD "tabmount" // WPA2 -> mind. 8 Zeichen

// Hall-Sensor zur iPad-Erkennung: aktiv LOW (LOW = iPad erkannt)
#define DEVICE_SENSOR_PIN 4

// Logo-LEDs (NeoPixel)
#define LED_PIN 6
#define NUMBER_OF_LEDS 4
#define LED_BRIGHTNESS 80

// Automatik-Modus: Logo-Farbe (nur aktiv, wenn KEIN iPad anliegt)
//   Person erkannt -> Weiss, keine Person -> Blau  (zum Tauschen hier aendern)
const uint8_t AUTO_PERSON_R = 255, AUTO_PERSON_G = 255, AUTO_PERSON_B = 255; // weiss
const uint8_t AUTO_IDLE_R = 0, AUTO_IDLE_G = 0, AUTO_IDLE_B = 255;           // blau

// Stepper-Motor (A4988) zur Display-Steuerung
#define STEP_PIN 9
#define DIR_PIN 10
#define STEPPER_ENABLE 8
#define STEPPER_SLEEP 15

// MCP4725 DAC zur Einstellung des Motorstroms (A4988 Vref)
#define DAC_I2C_ADDRESS 0x60
#define DAC_SDA_PIN 14
#define DAC_SCL_PIN 13
#define DAC_MOTOR_CURRENT 600 // 12-Bit-Default-Wert -> Vref fuer den Treiber
#define MOTOR_DAC_MIN 350     // erlaubtes Minimum (darunter zu wenig Drehmoment)
#define MOTOR_DAC_MAX 2000    // erlaubtes Maximum (darueber unnoetig Strom/Waerme)

// LD2410 Presence-Sensor (UART). Verschaltung gemaess main-Branch / Reference:
//   ESP RX 18 <- LD2410 TX, ESP TX 17 -> LD2410 RX, 256000 Baud (Serial1)
#define LD2410_SERIAL Serial1
#define LD2410_RX_PIN 18
#define LD2410_TX_PIN 17
#define LD2410_BAUD 256000

// Nach einer Motorbewegung den Radar fuer diese Zeit ignorieren: der Motor
// erzeugt selbst eine Bewegung, die der Sensor sonst als Person fehldeutet.
#define SENSOR_SETTLE_MS 2500

// ************************************************************************
// Globale Instanzen
// ************************************************************************

AsyncWebServer server(80);
AsyncWebSocket ws("/ws");

Adafruit_NeoPixel logoLED(NUMBER_OF_LEDS, LED_PIN, NEO_GRB + NEO_KHZ800);

Adafruit_MCP4725 dac;
TwoWire I2C = TwoWire(0);
// activationRevolutions=10, motorSteps=3500, speed=700
DisplayController displayController(STEP_PIN, DIR_PIN, STEPPER_ENABLE, STEPPER_SLEEP, 10, 3500, 700);

MyLD2410 presenceSensor(LD2410_SERIAL);

Preferences prefs; // persistenter Speicher (NVS) fuer den Display-Zustand

// ************************************************************************
// Laufzeit-Zustand
//
// Aenderungen werden ausschliesslich im loop() ausgewertet/gesendet.
// Die ISR und die (Async-)WebSocket-Handler setzen nur Flags/Wuensche.
// ************************************************************************

// --- Eingaenge (Sensoren) ---
volatile bool devicePresent = false; // Hall-Sensor: iPad liegt an
volatile bool stateDirty = true;     // true => Zustand an Clients senden

// --- Betriebsmodus + manuelle Sollwerte ---
// manualMode = false (Automatik) ist der Boot-Default. Im Automatik-Modus
// bestimmen die Sensoren Display und LED; im manuellen Modus der Nutzer.
volatile bool manualMode = false;
volatile bool manualDisplayOn = false;      // gewuenschter Display-Zustand (manuell)
uint8_t ledR = 255, ledG = 255, ledB = 255; // manuelle LED-Farbe
uint16_t motorCurrentDac = DAC_MOTOR_CURRENT; // DAC-Wert (0-4095) -> VREF -> Motorstrom
bool dacOk = false;                           // MCP4725 beim Init gefunden? (sonst kein Motorstrom)

// --- zuletzt an die LED geschriebener Zustand (idempotentes Schreiben) ---
bool appliedLedOn = false;
uint8_t appliedR = 0, appliedG = 0, appliedB = 0;

String sensorVersion = ""; // LD2410 Firmware-Version (einmalig bei Boot gelesen)

// --- LD2410 Empfindlichkeit pro Entfernungs-Gate ("Band") ---
// Der LD2410 unterteilt die Reichweite in 9 Gates (0-8) mit je einer Schwelle
// fuer Bewegung und Ruhe. Uebersteigt die Live-Energie eines Gates dessen
// Schwelle, gilt das Band als ausgeloest. Der Nutzer stellt diese Schwellen
// ("Soll") im Dashboard ein und sieht die Live-Energie der Baender.
//
// Schreibbefehle an den Sensor sind blockierend und regeln den Config-Mode
// selbst -> sie duerfen NUR aus dem loop() (einziger Radar-Kontext) laufen.
// Der WS-Handler hinterlegt daher nur die Wuensche; loop() schreibt sie.
const uint8_t LD2410_GATES = 9;
volatile bool gateWritePending[LD2410_GATES] = {false};
volatile uint8_t pendingMovingThr[LD2410_GATES] = {0};
volatile uint8_t pendingStatThr[LD2410_GATES] = {0};
// Gewuenschtes max. Gate (Reichweite, 0-8). -1 = kein ausstehender Wunsch.
volatile int pendingMaxGate = -1;

// Effektive (maskierte) Anwesenheit. Waehrend des Settle-Fensters nach einer
// Motorbewegung wird der Radar ignoriert und dieser letzte Wert eingefroren.
bool personDetected = false;
unsigned long sensorMaskUntil = 0;

// Drosselung der Live-Broadcasts der LD2410-Daten (Distanz aendert sich laufend)
unsigned long lastSensorBroadcast = 0;
const unsigned long SENSOR_BROADCAST_INTERVAL = 250; // ms -> max. 4 Updates/s

DeviceDetection deviceSensor(DEVICE_SENSOR_PIN, INPUT_PULLUP, devicePresent);

// ************************************************************************
// Hardware-Hilfsfunktionen
// ************************************************************************

// Schreibt die LED nur, wenn sich etwas geaendert hat (verhindert Flackern/Spam,
// da im loop() jede Iteration aufgerufen). on=false => LEDs aus.
void applyLed(bool on, uint8_t r, uint8_t g, uint8_t b)
{
  if (!on)
  {
    r = g = b = 0;
  }
  if (on == appliedLedOn && r == appliedR && g == appliedG && b == appliedB)
  {
    return;
  }
  for (int i = 0; i < NUMBER_OF_LEDS; i++)
  {
    logoLED.setPixelColor(i, logoLED.Color(r, g, b));
  }
  logoLED.show();
  appliedLedOn = on;
  appliedR = r;
  appliedG = g;
  appliedB = b;
}

// Callback der DeviceDetection (laeuft im ISR-Kontext) -> nur Flags setzen
void IRAM_ATTR onDevicePresenceChange(bool present)
{
  devicePresent = present;
  stateDirty = true;
}

// ************************************************************************
// Zustands-Serialisierung und Broadcast
// ************************************************************************

String buildStateJson()
{
  JsonDocument doc;
  doc["manual"] = manualMode;
  doc["present"] = devicePresent;
  doc["display"] = displayController.getActivationState();
  doc["sensorVersion"] = sensorVersion;

  // Live-Anwesenheit des LD2410 nur, wenn der Sensor erreichbar ist
  // (effektiver, waehrend Motorbewegungen maskierter Wert)
  if (sensorVersion.length() > 0)
  {
    doc["personPresent"] = personDetected;

    // Empfindlichkeit pro Gate ("Baender"): eingestellte Schwellen + Live-Energie.
    // Reine Reads (maxRange wurde beim Boot gesetzt) -> kein UART-IO hier.
    const MyLD2410::ValuesArray &movThr = presenceSensor.getMovingThresholds();
    const MyLD2410::ValuesArray &staThr = presenceSensor.getStationaryThresholds();
    const MyLD2410::ValuesArray &movEng = presenceSensor.getMovingSignals();
    const MyLD2410::ValuesArray &staEng = presenceSensor.getStationarySignals();
    doc["gates"] = LD2410_GATES;
    doc["maxGate"] = presenceSensor.getRange(); // hoechstes aktives Gate (Reichweite)
    JsonArray jMovThr = doc["movingThr"].to<JsonArray>();
    JsonArray jStaThr = doc["statThr"].to<JsonArray>();
    JsonArray jMovEng = doc["movingEnergy"].to<JsonArray>();
    JsonArray jStaEng = doc["statEnergy"].to<JsonArray>();
    for (byte i = 0; i < LD2410_GATES; i++)
    {
      jMovThr.add(movThr.values[i]);
      jStaThr.add(staThr.values[i]);
      jMovEng.add(movEng.values[i]);
      jStaEng.add(staEng.values[i]);
    }
  }

  char hex[8];
  snprintf(hex, sizeof(hex), "#%02x%02x%02x", ledR, ledG, ledB);
  doc["hex"] = hex; // manuelle Wunschfarbe (fuer den manuellen Modus)

  // Effektiv an der LED anliegende Farbe (inkl. schwarz = aus) -> Dashboard-Sync
  char ledHex[8];
  snprintf(ledHex, sizeof(ledHex), "#%02x%02x%02x", appliedR, appliedG, appliedB);
  doc["ledColor"] = ledHex;

  doc["dac"] = motorCurrentDac; // Motorstrom (VREF) als roher DAC-Wert 0-4095
  doc["dacOk"] = dacOk;         // false => DAC nicht gefunden, Motor ohne Strom

  String out;
  serializeJson(doc, out);
  return out;
}

void broadcastState()
{
  if (ws.count() > 0)
  {
    ws.textAll(buildStateJson());
  }
}

// ************************************************************************
// WebSocket: eingehende Befehle
// ************************************************************************

void handleCommand(const JsonDocument &doc)
{
  const char *type = doc["type"] | "";

  if (strcmp(type, "setManualMode") == 0)
  {
    bool on = doc["on"] | false;
    // Beim Wechsel in den manuellen Modus den aktuellen Display-Zustand
    // uebernehmen -> kein ueberraschender Motorlauf, nahtlose Weitersteuerung.
    if (on && !manualMode)
    {
      manualDisplayOn = displayController.getActivationState();
    }
    manualMode = on;
    stateDirty = true;
    DEBUG_SERIAL.printf("Modus: %s\n", manualMode ? "MANUELL" : "AUTOMATIK");
  }
  else if (strcmp(type, "setDisplay") == 0)
  {
    // Nur Sollwert setzen; wirksam erst durch die Policy (controlStep) im manuellen Modus
    manualDisplayOn = doc["on"] | false;
    stateDirty = true;
  }
  else if (strcmp(type, "setLed") == 0)
  {
    const char *hex = doc["hex"] | "";
    if (strlen(hex) == 6)
    {
      long value = strtol(hex, nullptr, 16);
      ledR = (value >> 16) & 0xFF;
      ledG = (value >> 8) & 0xFF;
      ledB = value & 0xFF;
      stateDirty = true; // angewendet wird in controlStep (nur manueller Modus)
    }
  }
  else if (strcmp(type, "setMotorCurrent") == 0)
  {
    long v = doc["value"] | (long)motorCurrentDac;
    if (v < MOTOR_DAC_MIN)
      v = MOTOR_DAC_MIN;
    if (v > MOTOR_DAC_MAX)
      v = MOTOR_DAC_MAX;
    motorCurrentDac = (uint16_t)v;
    dac.setVoltage(motorCurrentDac, false); // live setzen (nicht ins DAC-EEPROM)

    // NVS nur bei "save" (Slider losgelassen) schreiben -> schont den Flash
    if (doc["save"] | false)
    {
      prefs.putUShort("dacValue", motorCurrentDac);
      DEBUG_SERIAL.printf("Motorstrom gespeichert: DAC=%u\n", motorCurrentDac);
    }
    stateDirty = true;
  }
  else if (strcmp(type, "setGateThreshold") == 0)
  {
    // Schwelle(n) eines Gates setzen. Tatsaechlich geschrieben wird im loop()
    // (serviceGateWrites), da der Sensor nur aus EINEM Kontext bedient wird.
    int gate = doc["gate"] | -1;
    if (gate >= 0 && gate < LD2410_GATES)
    {
      // Fehlende Werte mit der aktuell gesetzten Schwelle auffuellen (cached Read).
      long mov = doc["moving"] | (long)presenceSensor.getMovingThresholds().values[gate];
      long sta = doc["stationary"] | (long)presenceSensor.getStationaryThresholds().values[gate];
      if (mov < 0) mov = 0;
      if (mov > 100) mov = 100;
      if (sta < 0) sta = 0;
      if (sta > 100) sta = 100;
      pendingMovingThr[gate] = (uint8_t)mov;
      pendingStatThr[gate] = (uint8_t)sta;
      gateWritePending[gate] = true;
    }
  }
  else if (strcmp(type, "setMaxGate") == 0)
  {
    // Reichweite (hoechstes aktives Gate) setzen. Anwendung im loop().
    int g = doc["value"] | -1;
    if (g >= 1 && g <= 8)
      pendingMaxGate = g;
  }
}

void onWsMessage(uint8_t *data, size_t len)
{
  JsonDocument doc;
  if (deserializeJson(doc, data, len))
  {
    return; // ungueltiges JSON ignorieren
  }
  handleCommand(doc);
}

void onWsEvent(AsyncWebSocket *server, AsyncWebSocketClient *client,
               AwsEventType type, void *arg, uint8_t *data, size_t len)
{
  switch (type)
  {
  case WS_EVT_CONNECT:
    // Neuem Client sofort den vollstaendigen Zustand schicken
    client->text(buildStateJson());
    break;

  case WS_EVT_DATA:
  {
    AwsFrameInfo *info = (AwsFrameInfo *)arg;
    if (info->final && info->index == 0 && info->len == len && info->opcode == WS_TEXT)
    {
      onWsMessage(data, len);
    }
    break;
  }

  case WS_EVT_DISCONNECT:
  case WS_EVT_PONG:
  case WS_EVT_ERROR:
    break;
  }
}

// ************************************************************************
// Initialisierungsfunktionen
// ************************************************************************

void initializeSerial()
{
  DEBUG_SERIAL.begin(115200);
  delay(100);
}

void initializeFileSystem()
{
  if (!LittleFS.begin(true))
  {
    DEBUG_SERIAL.println("LittleFS konnte nicht gemountet werden!");
  }
}

void initializeSensors()
{
  deviceSensor.beginOutputObservation(onDevicePresenceChange);
  devicePresent = deviceSensor.isPresent();
}

void initializePresenceSensor()
{
  LD2410_SERIAL.begin(LD2410_BAUD, SERIAL_8N1, LD2410_RX_PIN, LD2410_TX_PIN);
  delay(200); // dem Sensor nach dem Power-up Zeit geben

  // begin() antwortet beim Kaltstart nicht immer sofort -> mehrere Versuche
  const int maxAttempts = 5;
  for (int attempt = 1; attempt <= maxAttempts; attempt++)
  {
    if (presenceSensor.begin())
    {
      sensorVersion = presenceSensor.getFirmware();
      DEBUG_SERIAL.printf("LD2410 verbunden (Versuch %d). Firmware: %s\n", attempt, sensorVersion.c_str());

      // Aktuelle Gate-Schwellen einlesen (setzt maxRange != 0, sodass die
      // Getter spaeter KEIN UART-IO mehr ausloesen -> aus WS-Kontext gefahrlos).
      presenceSensor.requestParameters();
      // Engineering-Mode: Sensor streamt zusaetzlich die Live-Energie pro Gate.
      presenceSensor.enhancedMode(true);
      return;
    }
    DEBUG_SERIAL.printf("LD2410 Init fehlgeschlagen (Versuch %d/%d)\n", attempt, maxAttempts);
    delay(300);
  }

  sensorVersion = "";
  DEBUG_SERIAL.println("LD2410 nicht erreichbar!");
}

void initializeLED()
{
  logoLED.begin();
  logoLED.setBrightness(LED_BRIGHTNESS);
  applyLed(false, 0, 0, 0); // initial aus; controlStep() setzt den echten Zustand
}

void initializeMotorControl()
{
  pinMode(STEPPER_SLEEP, OUTPUT);
  digitalWrite(STEPPER_SLEEP, HIGH);

  pinMode(STEPPER_ENABLE, OUTPUT);
  digitalWrite(STEPPER_ENABLE, HIGH);

  I2C.begin(DAC_SDA_PIN, DAC_SCL_PIN);
  dacOk = dac.begin(DAC_I2C_ADDRESS, &I2C);
  if (!dacOk)
  {
    DEBUG_SERIAL.println("WARNUNG: MCP4725 (DAC) nicht gefunden -> Motor erhaelt keinen Strom!");
  }

  prefs.begin("tabmount", false);

  // Zuletzt eingestellten Motorstrom (VREF) wiederherstellen
  motorCurrentDac = prefs.getUShort("dacValue", DAC_MOTOR_CURRENT);
  dac.setVoltage(motorCurrentDac, false);
  DEBUG_SERIAL.printf("Motorstrom (DAC) gesetzt: %u\n", motorCurrentDac);

  // Zuletzt persistierten Display-Zustand wiederherstellen, OHNE den Motor zu
  // bewegen. Der Magnet behaelt seine physische Position ueber Reboots hinweg;
  // so bleiben Firmware-Zustand und Realitaet konsistent und der Motor faehrt
  // nicht erneut gegen den Anschlag.
  bool storedDisplay = prefs.getBool("displayOn", false);
  displayController.setActivationState(storedDisplay);
  manualDisplayOn = storedDisplay; // sinnvoller Startwert fuer den manuellen Modus
  DEBUG_SERIAL.printf("Display-Zustand wiederhergestellt: %s\n", storedDisplay ? "EIN" : "AUS");
}

// Oeffnet den Konfigurations-Access-Point. SSID enthaelt eine geraetespezifische
// Hex-Kennung (aus der eFuse-MAC), damit mehrere Geraete unterscheidbar sind.
void initializeAccessPoint()
{
  char ssid[32];
  // Geraetespezifischer Teil der MAC = obere 3 Bytes. Die unteren 3 Bytes sind
  // der herstellergleiche OUI-Praefix und waeren bei baugleichen Boards identisch.
  uint32_t id = (uint32_t)((ESP.getEfuseMac() >> 24) & 0xFFFFFF);
  snprintf(ssid, sizeof(ssid), AP_SSID_PREFIX "%06X", id);

  WiFi.mode(WIFI_AP);
  WiFi.softAP(ssid, AP_PASSWORD);

  DEBUG_SERIAL.printf("AP gestartet: %s (PW: %s)\n", ssid, AP_PASSWORD);
  DEBUG_SERIAL.print("AP-IP-Adresse: ");
  DEBUG_SERIAL.println(WiFi.softAPIP());

  if (MDNS.begin(HOSTNAME))
  {
    MDNS.addService("http", "tcp", 80);
    DEBUG_SERIAL.printf("mDNS aktiv: http://%s.local\n", HOSTNAME);
  }
}

void initializeWebServer()
{
  ws.onEvent(onWsEvent);
  server.addHandler(&ws);

  // Statische Web-Assets (index.html, style.css, app.js) aus dem LittleFS.
  // Waehrend der Entwicklung NICHT cachen, damit Browser immer die aktuelle
  // Version laden (verhindert stale/mismatched HTML+JS).
  server.serveStatic("/", LittleFS, "/")
      .setDefaultFile("index.html")
      .setCacheControl("no-store");

  server.begin();
  DEBUG_SERIAL.println("HTTP-Server gestartet");
}

// Schreibt ausstehende Gate-Schwellen auf den Sensor. Laeuft im loop() (einziger
// Radar-Kontext). setGateParameters() ist blockierend und regelt den Config-Mode
// selbst -> daher pro Durchlauf nur EIN Gate, damit der loop reaktionsfaehig bleibt.
void serviceGateWrites()
{
  if (sensorVersion.length() == 0)
    return;

  // Reichweite (max. Gate) zuerst anwenden, falls gewuenscht. setMaxGate setzt
  // dasselbe Gate fuer Bewegung und Ruhe und behaelt das No-One-Window bei.
  if (pendingMaxGate >= 0)
  {
    byte g = (byte)pendingMaxGate;
    pendingMaxGate = -1;
    bool ok = presenceSensor.setMaxGate(g, g, presenceSensor.getNoOneWindow());
    DEBUG_SERIAL.printf("Max-Gate gesetzt: %u (%s)\n", g, ok ? "OK" : "FAIL");
    presenceSensor.enhancedMode(true);
    stateDirty = true;
    return;
  }

  for (byte g = 0; g < LD2410_GATES; g++)
  {
    if (!gateWritePending[g])
      continue;

    uint8_t mov = pendingMovingThr[g];
    uint8_t sta = pendingStatThr[g];
    gateWritePending[g] = false; // vor dem Schreiben loeschen (neuere Wuensche gehen nicht verloren)

    bool ok = presenceSensor.setGateParameters(g, mov, sta);
    DEBUG_SERIAL.printf("Gate %u Schwellen: mov=%u sta=%u (%s)\n", g, mov, sta, ok ? "OK" : "FAIL");

    // Die Config-Session kann den Engineering-Mode beenden -> wieder aktivieren,
    // damit weiterhin Live-Energie pro Gate gestreamt wird.
    presenceSensor.enhancedMode(true);
    stateDirty = true;
    return; // nur ein Gate pro loop()-Durchlauf
  }
}

// ************************************************************************
// Steuerlogik (Policy)
//
// Einzige Stelle, die die Aktoren (Display-Motor, Logo-LED) ansteuert.
// Berechnet aus Modus + Sensoren die Soll-Ausgaenge und wendet sie an.
// Wird ausschliesslich im loop() aufgerufen (Motorbewegung ist blockierend).
// ************************************************************************
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
void loop()
{
  // LD2410-Datenframes einlesen. Bei neuen Daten wird ein Broadcast angestossen,
  // jedoch gedrosselt, da sich Distanz/Status laufend aendern.
  if (presenceSensor.check() == MyLD2410::Response::DATA)
  {
    unsigned long now = millis();
    if (now - lastSensorBroadcast >= SENSOR_BROADCAST_INTERVAL)
    {
      lastSensorBroadcast = now;
      stateDirty = true;
    }
  }

  // Ausstehende Gate-Schwellen auf den Sensor schreiben (ein Gate pro Durchlauf).
  serviceGateWrites();

  // Steuerlogik: Soll-Ausgaenge berechnen und anwenden (Motor/LED).
  controlStep();

  // Zustandsaenderungen an alle Clients pushen.
  if (stateDirty)
  {
    stateDirty = false;
    broadcastState();
  }

  ws.cleanupClients();
}

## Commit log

2024-11-16 Add LD2410 sensor library as submodule
2024-11-16 Ändere Standardumgebung von 'ota' zu 'usb-fast' und passe Umgebungsnamen an
2024-11-17 Optimierung der Animation des Dashboards
2024-12-27 Restruktur Repo
    [Gehäuse Deckel.stp, Gehäuse Infill.stp, Gehäuse.stp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]
2026-04-11 Komprimierung der Bilder
2026-06-27 Presence-Sensor-Konfiguration und Dashboard-Überarbeitung
    Dashboard:
    - Presence-Sensor-Block zeigt jetzt den Verbindungsstatus (Verbunden/Offline);
    Firmware-Version in eine eigene Detailseite verschoben (Zahnrad-Icon öffnet
    die Ansicht, Zurück-Button führt zurück)
    - Neue Detailseite zum Einstellen der LD2410-Empfindlichkeit pro Gate ("Bänder"):
    je Band zwei Kanäle (Dyn./Stat.) mit Live-Energie-Balken und einstellbarer
    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
2026-06-27 Firmware-README korrigieren und secrets-Altlasten entfernen
    - Firmware/README: falsche Submodule-Anweisung ersetzt durch reale
    PlatformIO-Setup-, Flash- und Konfigurationsschritte (kein Submodule-Schritt,
    lib_deps werden automatisch geladen, zwei Upload-Ziele, dauerhafter AP)
    - secrets.example.h entfernt und src/secrets.h aus .gitignore genommen:
    der AP-only-Rewrite nutzt keine WLAN-STA-Zugangsdaten mehr

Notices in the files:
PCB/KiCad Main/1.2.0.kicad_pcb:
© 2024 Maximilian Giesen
